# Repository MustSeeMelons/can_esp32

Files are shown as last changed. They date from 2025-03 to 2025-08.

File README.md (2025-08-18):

# CAN ESP32

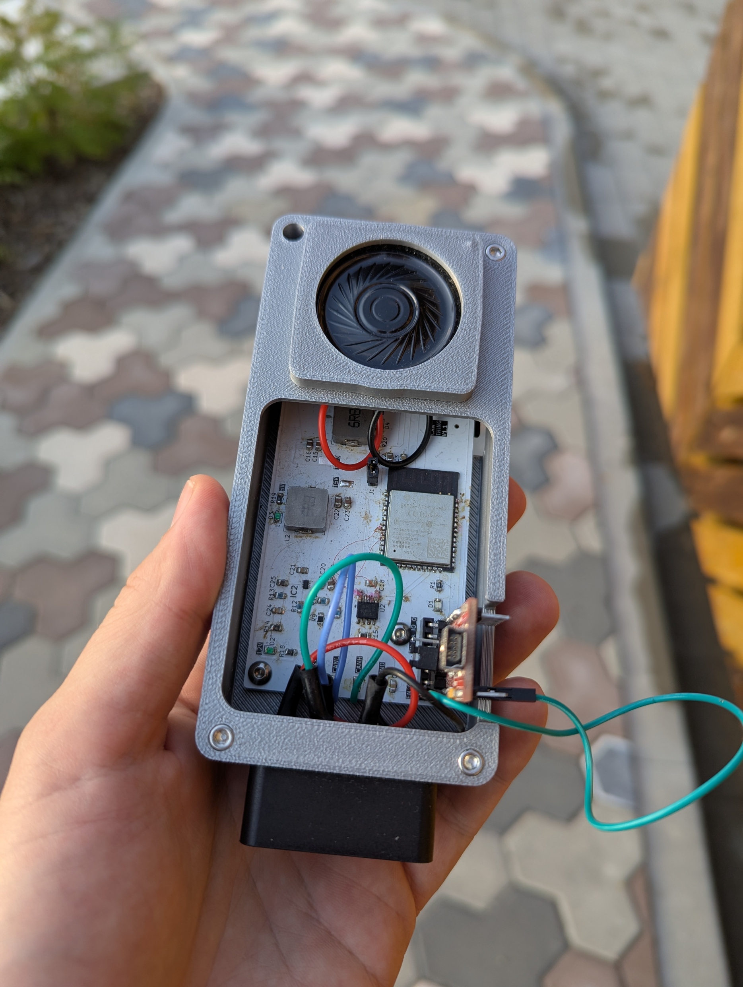
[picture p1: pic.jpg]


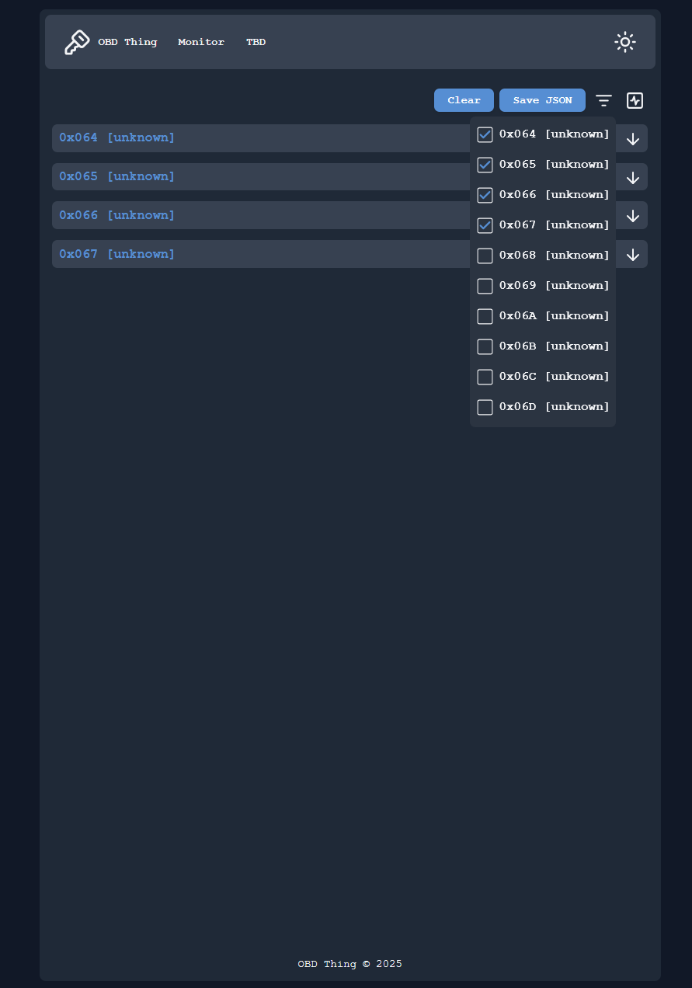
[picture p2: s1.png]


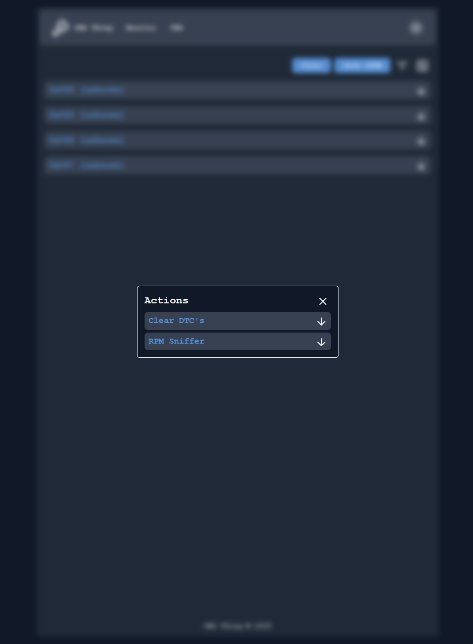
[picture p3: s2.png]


The loose wire goes to 3rd pin from the bottom (DTR?).

## Summary

New cars do chimes when turning on the engine. My '06 Focus does not. This device aims to rectify that!
An ESP32 with an micro sd card reader, paired with a MAX9860 to play .wav files upon receiving certain CAN messages.
CAN connection handled by the TJA1050. Powered from the OBD2 port 12V rail, with two buck converters for 5V and 3V.

Is an AP that serves a Preact App for listening in on the CAN network via a websocket connection.

Avaialble through `obd2.local` with the help of mdns!

On plugging in plays the windows XP startup sound.

I don't get any OBD responses from my 2006 Focus, but I can clear DTC's!

Would need to decode raw CAN frames to make sense of anything.

## TODO
- [FW/FE] Read DTC
- [FW] Play audio on startup (800RPM) and shutdown (?) (0RPM).
- [FW] SD Card logger.
- [FE][FW] Oil Temp request/response, visualization.
- [XX] Update PCB [IC<>IC level shifter, CAN caps, 32[TX], 33[RX]]
- [FE] GZIP the Preact app
- [FW] Spiffs for web app storage?

- Plug in device to gather more data points - need to decipher the messages.

## Notes to future self

- Implement the upload mechanism that all ESP32 baords use. Turning things on/off is annoying.
- Serial monitoring during operation would be great!

## How to flash

1. Connect the FTDI FT232RL and power it on.
2. Connect 12V, GND leads and power on the power supply.
3. Turn off both, turn back the power supply.

### Dev Board

Keep down the boot button while powering on.

## Julie OBD2 emulator

RED: VCC
BLUE: GND
GREEN: CODE (UNCONNECTED/GND)
BLACK: CAN-H
WHITE: CAN-L

Sketchy link: https://lisaiauto.ru/universalnyj-emulyator-julie-of80-manual-po-nastrojke-i-podklyucheniyu/

## SPIFFS

## OBDII Response addresses 

`0x7DF` is a broadcast to all devices.
`0x7E8` should be the engine
`0x7e9` should be transmission

## Websocket

- Must enable WS in SDK
- Must increase HTTP URI Length in SDK

## TJA1050

TX & RX should be swapped when connecting - RX goes to TX, RX to TX as usual.

## SD Card

Files present on the SD card at `/`

- xp/oxp.wav
- xp/vistashutdown.wav

## VSC

Instal LLVM and use theclang-format extension for formatting. [link](https://github.com/llvm/llvm-project/releases/tag/llvmorg-20.1.0)

## IDF

ESP-IDF projects are built using CMake. The project build configuration is contained in `CMakeLists.txt`
files that provide set of directives and instructions describing the project's source files and targets
(executable, library, or both).

Below is short explanation of remaining files in the project folder.

```
├── CMakeLists.txt
├── main
│   ├── CMakeLists.txt
│   └── main.c
└── README.md                  This is the file you are currently reading
```

Additionally, the sample project contains Makefile and component.mk files, used for the legacy Make based build system.
They are not used or needed when building with CMake and idf.py.

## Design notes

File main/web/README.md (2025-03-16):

# Icons

https://lucide.dev/icons/

# TODO

- Define breakpoints & use them
- Make a button component
- Route error boundary?
- Inline everything into single HTML

# DONE

- Move theme into seperate component
- Make a card component
- Make a nice 404

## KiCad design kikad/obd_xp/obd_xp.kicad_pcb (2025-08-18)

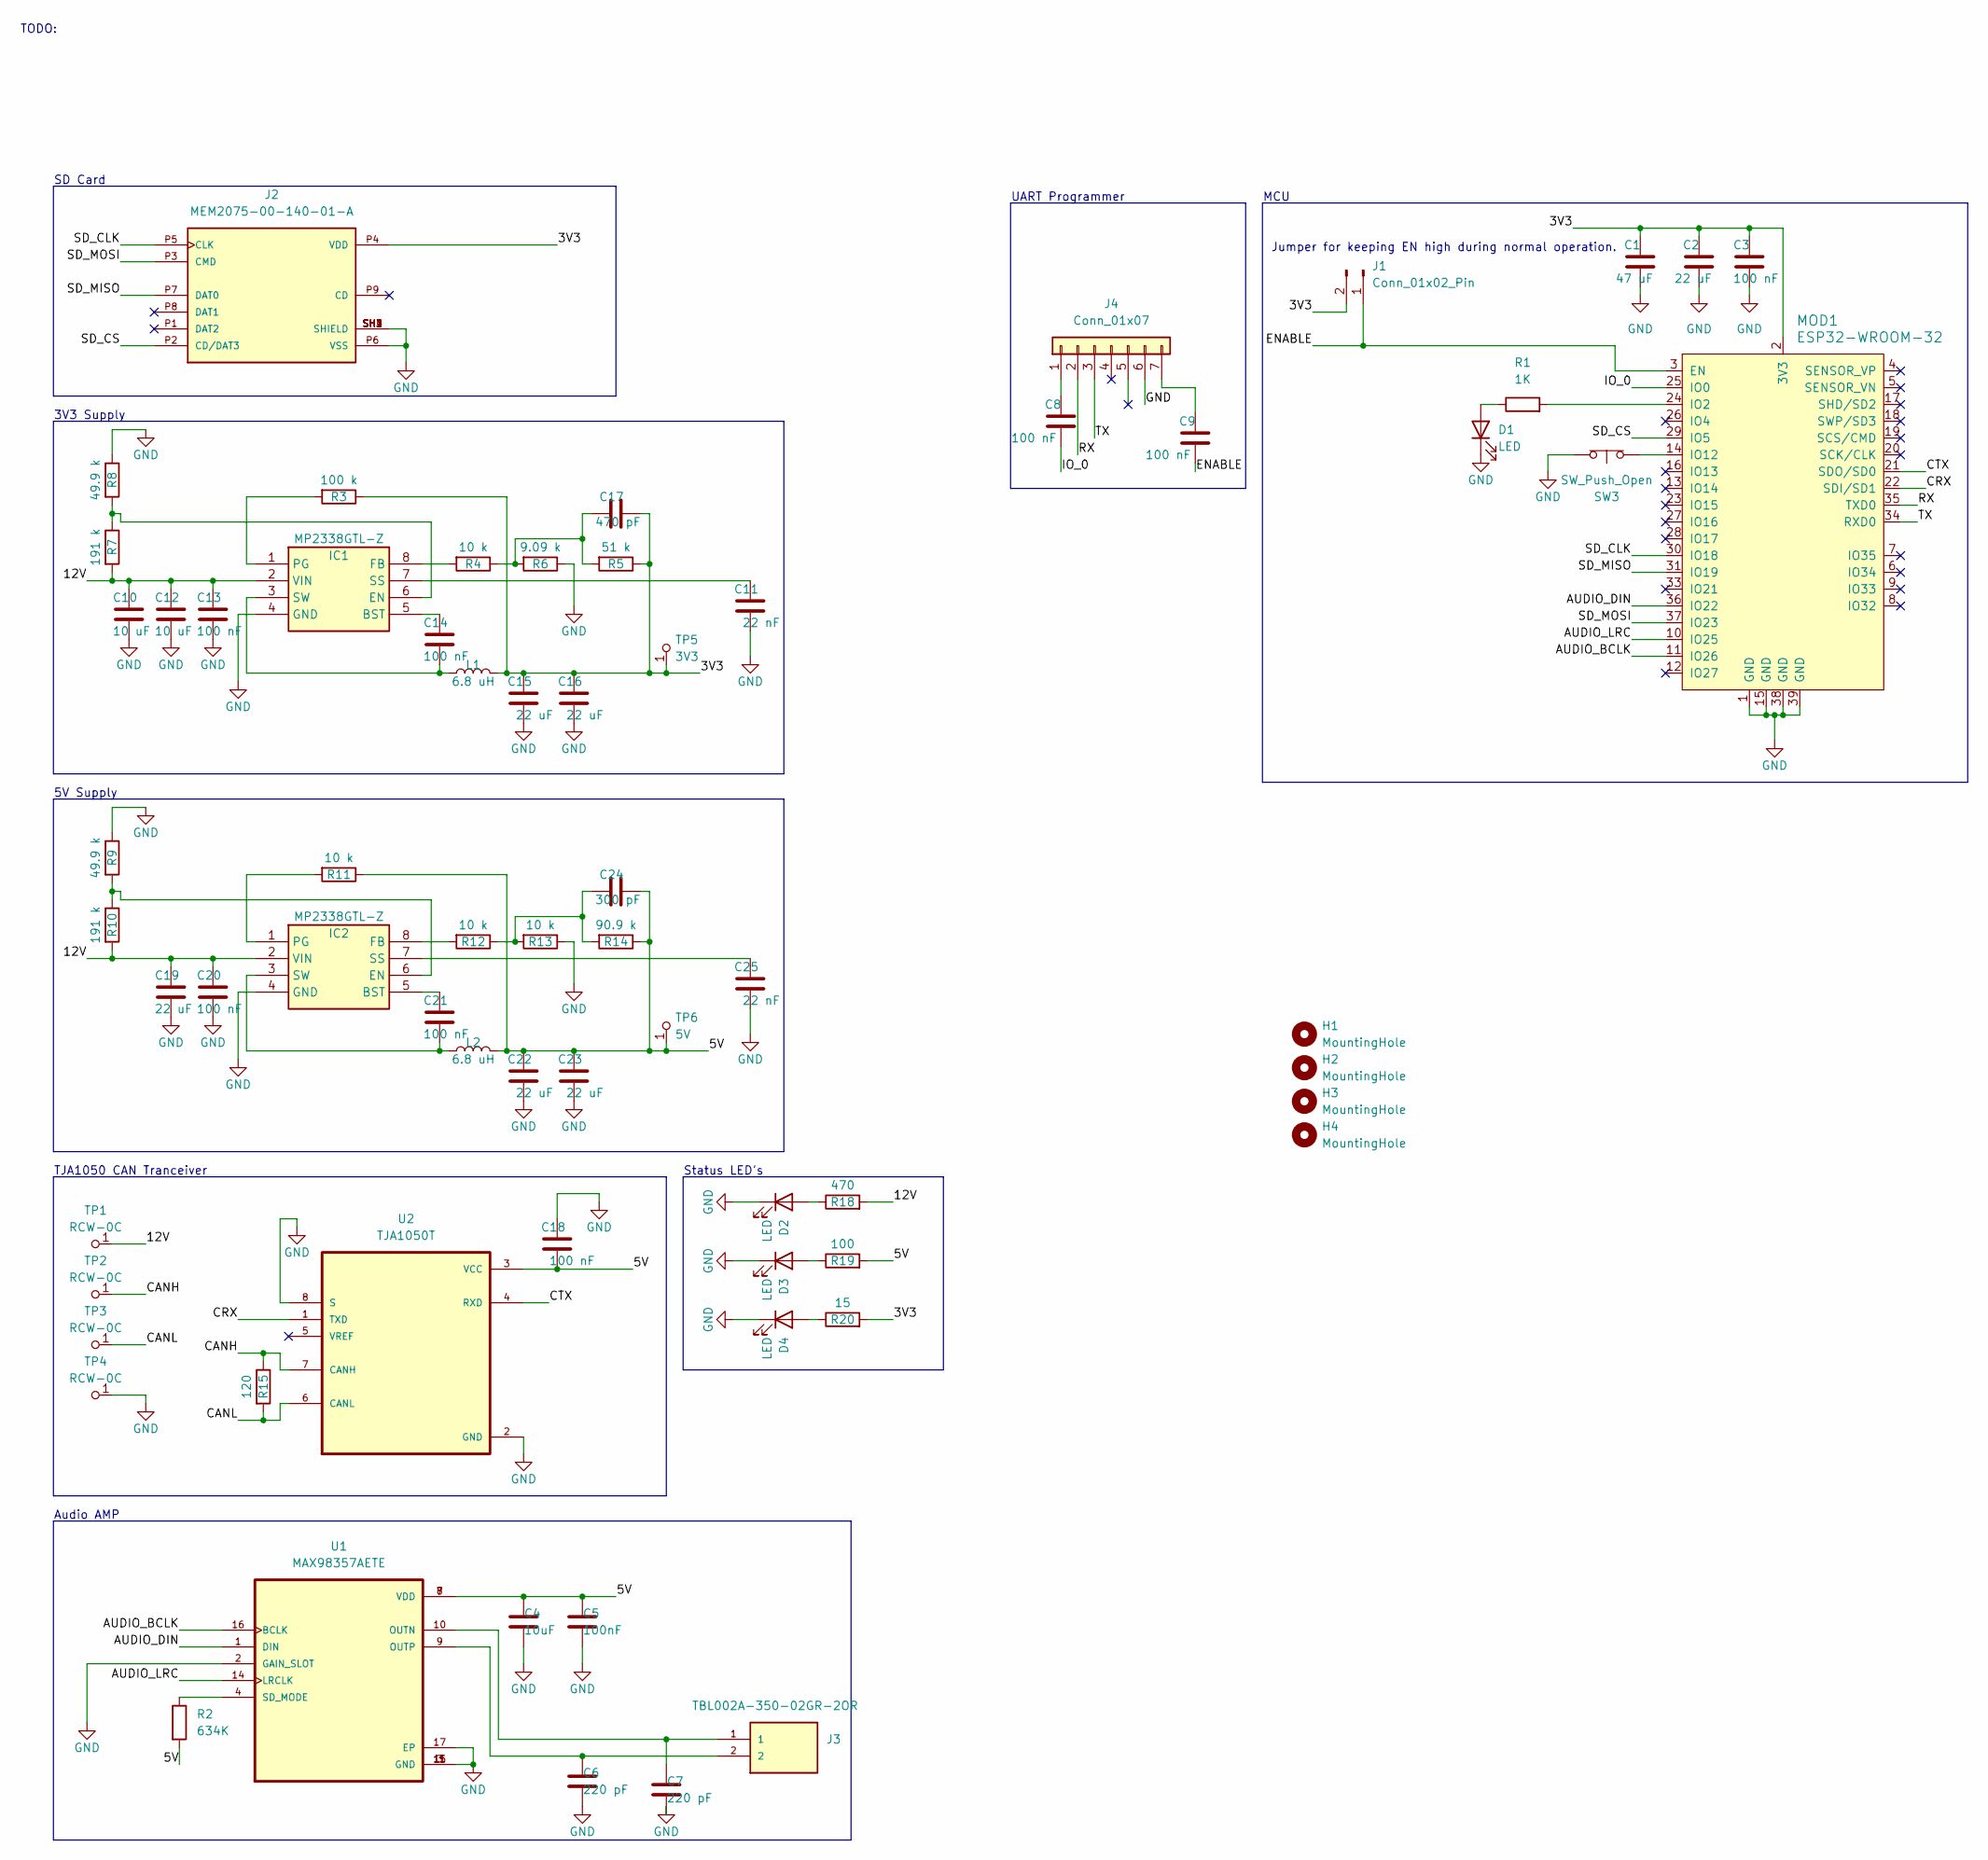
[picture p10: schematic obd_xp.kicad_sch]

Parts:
C1: 47 uF; C_0805_2012Metric
C2, C15, C16, C19, C22, C23: 22 uF; C_0805_2012Metric
C3, C8, C9, C13, C14, C18, C20, C21: 100 nF; C_0805_2012Metric
C4: 10uF; C_0805_2012Metric
C5: 100nF; C_0805_2012Metric
C6, C7: 220 pF; C_0805_2012Metric
C10, C12: 10 uF; C_0805_2012Metric
C11, C25: 22 nF; C_0805_2012Metric
C17: 470 pF; C_0805_2012Metric
C24: 300 pF; C_0805_2012Metric
D1, D2, D3, D4: LED; LED_0805_2012Metric
H1, H2, H3, H4: MountingHole; MountingHole_3.2mm_M3
IC1, IC2: MP2338GTL-Z; MP2338GTLZ; Mouser Part Number 946-MP2338GTL-Z
J1: Conn_01x02_Pin; PinHeader_1x02_P2.54mm_Vertical
J2: MEM2075-00-140-01-A; GCT_MEM2075-00-140-01-A; PARTREV A
J3: TBL002A-350-02GR-2OR; CUI_TBL002A-350-02GR-2OR; PARTREV 1.0
J4: Conn_01x07; PinHeader_1x07_P2.54mm_Vertical
L1, L2: 6.8 uH; L_SOREDE_SNR.1050_10x10x5mm
MOD1: ESP32-WROOM-32; ESP32-WROOM-32D; MPN ESP32-WROOM-32; Digi-Key_PN 1904-1010-1-ND
R1: 1K; R_0805_2012Metric
R2: 634K; R_0805_2012Metric
R3: 100 k; R_0805_2012Metric
R4, R11, R12, R13: 10 k; R_0805_2012Metric
R5: 51 k; R_0805_2012Metric
R6: 9.09 k; R_0805_2012Metric
R7, R10: 191 k; R_0805_2012Metric
R8, R9: 49.9 k; R_0805_2012Metric
R14: 90.9 k; R_0805_2012Metric
R15: 120; R_0805_2012Metric
R18: 470; R_0805_2012Metric
R19: 100; R_0805_2012Metric
R20: 15; R_0805_2012Metric
SW3: SW_Push_Open; SW_PUSH_6mm
TP1, TP2, TP3, TP4: RCW-0C; PROBE_PAD_1206; MPN RCW-0C; Digi-Key_PN A106146CT-ND
TP5: 3V3; PROBE_PAD_1206; MPN RCW-0C; Digi-Key_PN A106146CT-ND
TP6: 5V; PROBE_PAD_1206; MPN RCW-0C; Digi-Key_PN A106146CT-ND
U1: MAX98357AETE; QFN50P300X300X80-17N
U2: TJA1050T; SOIC127P599X175-8N

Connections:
/3V3: C1.1, C2.1, C3.1, C15.1, C16.1, C17.2, J1.2, J2.P4 (VDD), L1.2, MOD1.2 (3V3), R3.1, R5.1, R20.2, TP5.1
/5V: C4.1, C5.1, C18.2, C22.1, C23.1, C24.2, L2.2, R2.2, R11.1, R14.1, R19.2, TP6.1, U1.7 (VDD), U1.8 (VDD), U2.3 (VCC)
/12V: C10.1, C12.1, C13.1, C19.1, C20.1, IC1.2 (VIN), IC2.2 (VIN), R7.2, R10.2, R18.2, TP1.1
/AUDIO_BCLK: MOD1.11 (IO26), U1.16 (BCLK)
/AUDIO_DIN: MOD1.36 (IO22), U1.1 (DIN)
/AUDIO_LRC: MOD1.10 (IO25), U1.14 (LRCLK)
/CANH: R15.1, TP2.1, U2.7 (CANH)
/CANL: R15.2, TP3.1, U2.6 (CANL)
/CRX: MOD1.22 (SDI/SD1), U2.1 (TXD)
/CTX: MOD1.21 (SDO/SD0), U2.4 (RXD)
/ENABLE: C9.2, J1.1, MOD1.3 (EN)
/IO_0: C8.2, MOD1.25 (IO0)
/RX: J4.2, MOD1.35 (TXD0)
/SD_CLK: J2.P5 (CLK), MOD1.30 (IO18)
/SD_CS: J2.P2 (CD/DAT3), MOD1.29 (IO5)
/SD_MISO: J2.P7 (DAT0), MOD1.31 (IO19)
/SD_MOSI: J2.P3 (CMD), MOD1.37 (IO23)
/TX: J4.3, MOD1.34 (RXD0)
GND: C1.2, C2.2, C3.2, C4.2, C5.2, C6.2, C7.2, C10.2, C11.2, C12.2, C13.2, C15.2, C16.2, C18.1, C19.2, C20.2, C22.2, C23.2, C25.2, D1.1 (K), D2.1 (K), D3.1 (K), D4.1 (K), IC1.4 (GND), IC2.4 (GND), J2.P6 (VSS), J2.SH1 (SHIELD), J2.SH2 (SHIELD), J2.SH3 (SHIELD), J2.SH4 (SHIELD), J4.6, MOD1.1 (GND), MOD1.15 (GND), MOD1.38 (GND), MOD1.39 (GND), R6.1, R8.1, R9.1, R13.1, SW3.1 (A), TP4.1, U1.2 (GAIN_SLOT), U1.3 (GND), U1.11 (GND), U1.15 (GND), U1.17 (EP), U2.2 (GND), U2.8 (S)
unnamed: C17.1, R4.1, R5.2, R6.2
unnamed: C24.1, R12.1, R13.2, R14.2
unnamed: D1.2 (A), R1.1
unnamed: D2.2 (A), R18.1
unnamed: D3.2 (A), R19.1
unnamed: D4.2 (A), R20.1
unnamed: C14.1, IC1.5 (BST)
unnamed: IC1.6 (EN), R7.1, R8.2
unnamed: IC1.8 (FB), R4.2
unnamed: IC1.1 (PG), R3.2
unnamed: C11.1, IC1.7 (SS)
unnamed: C14.2, IC1.3 (SW), L1.1
unnamed: C21.1, IC2.5 (BST)
unnamed: IC2.6 (EN), R9.2, R10.1
unnamed: IC2.8 (FB), R12.2
unnamed: IC2.1 (PG), R11.2
unnamed: C25.1, IC2.7 (SS)
unnamed: C21.2, IC2.3 (SW), L2.1
unnamed: C8.1, J4.1
unnamed: C9.1, J4.7
unnamed: MOD1.24 (IO2), R1.2
unnamed: MOD1.14 (IO12), SW3.2 (B)
unnamed: C7.1, J3.1, U1.10 (OUTN)
unnamed: C6.1, J3.2, U1.9 (OUTP)
unnamed: R2.1, U1.4 (SD_MODE)

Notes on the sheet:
3V3 Supply
Status LED's
TODO:
TJA1050 CAN Tranceiver
Jumper for keeping EN high during normal operation.
5V Supply
SD Card
Audio AMP
UART Programmer
MCU

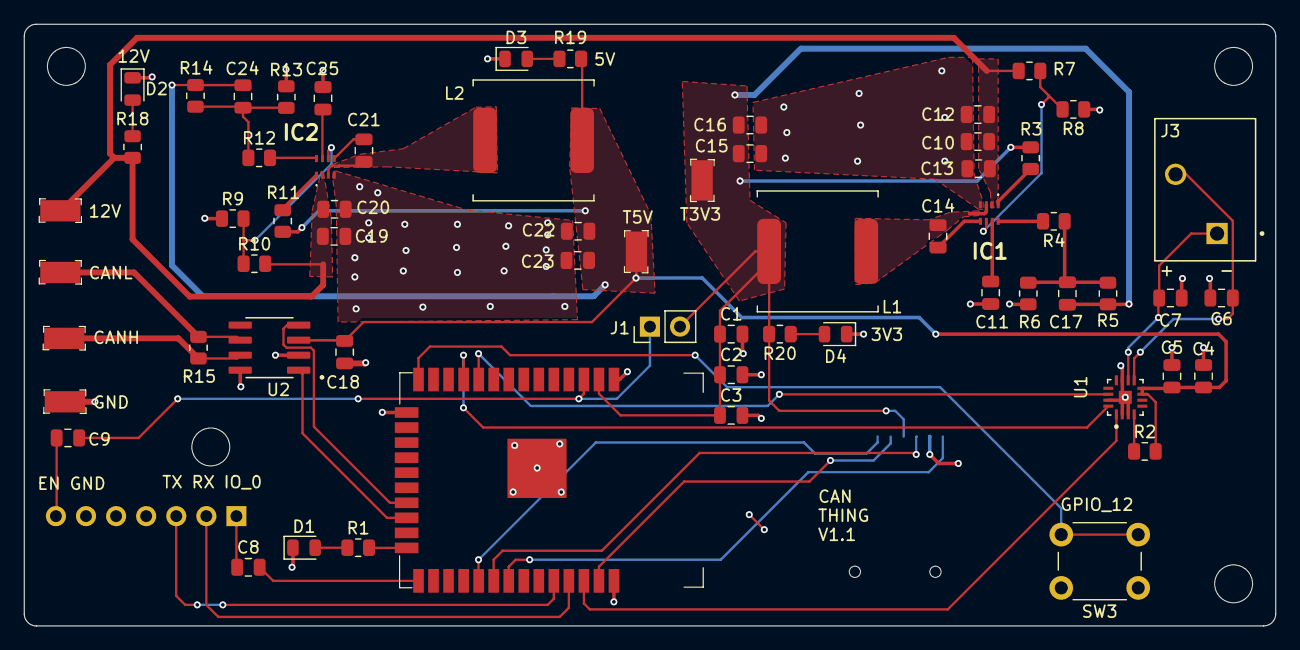
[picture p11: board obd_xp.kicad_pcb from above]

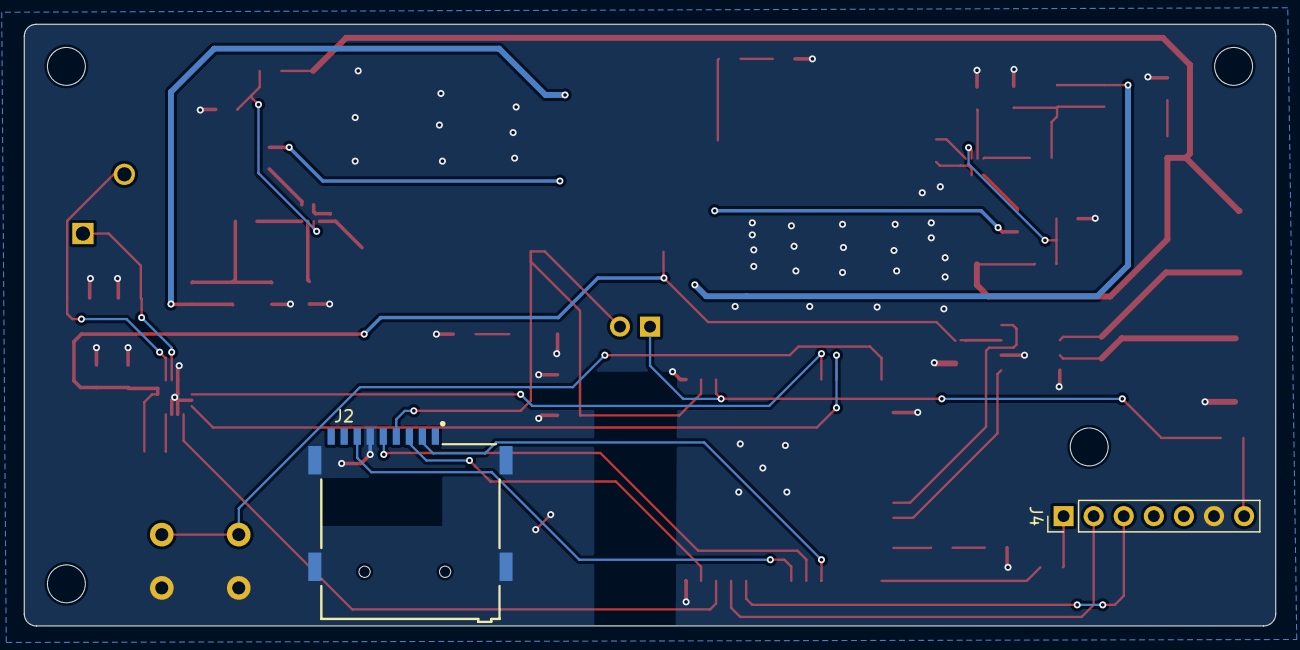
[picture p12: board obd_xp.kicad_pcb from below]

Board: 2 copper layers, 105.7 x 50.8 mm, 69 parts (2 on the bottom side), 44 nets.

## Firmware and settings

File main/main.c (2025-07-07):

#include "driver/twai.h"
#include "esp_spiffs.h"
#include "freertos/FreeRTOS.h"
#include "freertos/task.h"
#include <stdio.h>

#include "audio/audio.h"
#include "http/http_server.h"
#include "i2s/i2s.h"
#include "mdns_service/mdns_service.h"
#include "obd/obd.h"
#include "sd/sd.h"
#include "wifi/wifi.h"

// TODO add err check for the rest of inits
void app_main() {
    esp_err_t ret = -1;

    ret = sd_init();

    if (ret != ESP_OK) {
        return;
    }

    audio_init();

    i2s_init();

    obd_init();

    obd_task_start();

    wifi_init();

    http_server_init();

    mnds_init();

    // xp_shutdown, XXX this does not play for some reason
    audio_play_wav("xp_logon.wav");
}

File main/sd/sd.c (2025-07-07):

#include "sd.h"

static const char *TAG = "SD";

static uint8_t max_mount_retries = 3;

// For recieving files to read
static QueueHandle_t sd_command_queue_handle = NULL;
static TaskHandle_t sd_task_handle = NULL;

static esp_err_t sd_mount_fs() {
    esp_err_t ret;

    // clang-format off
    esp_vfs_fat_sdmmc_mount_config_t mount_config = {
        .format_if_mount_failed = false,
        .max_files = 5
    };
    // clang-format on

    sdmmc_card_t *card;
    const char mount_point[] = MOUNT_POINT;
    ESP_LOGI(TAG, "Initializing SD card");

    sdmmc_host_t host = SDSPI_HOST_DEFAULT();

    spi_bus_config_t bus_cfg = {
        .mosi_io_num = SPI_MOSI,
        .miso_io_num = SPI_MISO,
        .sclk_io_num = SPI_SCK,
        .quadwp_io_num = -1,
        .quadhd_io_num = -1,
        .max_transfer_sz = 2048,
    };

    ret = spi_bus_initialize(host.slot, &bus_cfg, SDSPI_DEFAULT_DMA);

    if (ret != ESP_OK) {
        ESP_LOGI(TAG, "Failed to initialize SPI");
        return ret;
    } else {
        ESP_LOGI(TAG, "SPI initialized");
    }

    sdspi_device_config_t slot_config = SDSPI_DEVICE_CONFIG_DEFAULT();
    slot_config.gpio_cs = SD_CS;
    slot_config.host_id = host.slot;

    ret = esp_vfs_fat_sdspi_mount(mount_point, &host, &slot_config, &mount_config, &card);

    if (ret != ESP_OK) {
        ESP_LOGI(TAG, "Failed to mount FS");
        // De-init spi don't care it it fails
        spi_bus_free(host.slot);
        return ret;
    } else {
        ESP_LOGI(TAG, "FS mounted");
    }

    // sdmmc_card_print_info(stdout, card);

    return ESP_OK;
}

static void sd_task(void *pvParameter) {
    sd_message_t msg;

    for (;;) {
        if (xQueueReceive(sd_command_queue_handle, &msg, portMAX_DELAY)) {
            switch (msg.msg_id) {
            case SD_READ_FILE:
                char full_path[MAX_PATH];
                snprintf(full_path, sizeof(full_path), "%s/%s", MOUNT_POINT, msg.filename);

                FILE *f = fopen(full_path, "rb");

                if (!f) {
                    ESP_LOGI(TAG, "Failed to open file! %s", full_path);
                    break;
                }

                ESP_LOGI(TAG, "Playing: %s", full_path);

                // TODO read header and re-configure i2s
                fseek(f, 0, SEEK_SET);
                uint8_t header[44];
                fread(header, 1, 44, f);

                while (true) {
                    i2s_audio_message_t msg;

                    BaseType_t status = audio_get_free_buffer(&msg);

                    if (status == pdFALSE) {
                        ESP_LOGI(TAG, "SD Failed to get free buffer");
                        vTaskDelay(1);
                        continue;
                    }

                    size_t bytes_read = fread(msg.bytes, sizeof(uint8_t), BUFFER_SIZE, f);
                    msg.len = bytes_read;

                    i2s_send_audio_buffer(msg);

                    if (bytes_read == 0) {
                        break;
                    }

                    vTaskDelay(1);
                }

                fclose(f);

                break;
            default:
                break;
            }
        }
    }
}

esp_err_t sd_init() {
    esp_err_t ret = -1;
    uint8_t retries = 0;

    while (ret != ESP_OK && retries < max_mount_retries) {
        ret = sd_mount_fs();
        retries++;
    }

    if (ret != ESP_OK) {
        ESP_LOGI(TAG, "Init failed.");
        return ret;
    }

    sd_command_queue_handle = xQueueCreate(3, sizeof(sd_message_t));

    // clang-format off
    xTaskCreatePinnedToCore(
        &sd_task,
        "sd_task",
        SD_TASK_STACK_SIZE,
        NULL,
        SD_TASK_PRIORITY,
        &sd_task_handle,
        SD_TASK_CODE_ID
    );
    // clang-format on

    return ret;
}

BaseType_t sd_send_message(sd_message_t msg) {
    return xQueueSend(sd_command_queue_handle, &msg, portMAX_DELAY);
}

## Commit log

2025-03-16 Serve Preact app
    [partitions.csv]
2025-07-07 Clear button + transparent button type
2025-07-07 Fix SD SPI bad retry
    [main.c, sd.c]
2025-08-01 Send CAN message (successfully)
    [partitions.csv]
2025-08-06 Clear DTC button flow
2025-08-12 Checkbox & message filter
